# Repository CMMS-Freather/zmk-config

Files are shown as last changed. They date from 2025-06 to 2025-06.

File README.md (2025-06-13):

# HHKB Pro 2 with ZMK firmware

This project provides an out-of-tree Zephyr module and shield definition
for the HHKB Pro2 daugther board.

The `hhkb_pro2` shield defines the default HHKB keymap and `zmk,kscan`
chosen. Any board can use the `hhkb_pro2` shield by defining the
`hhkb_pro2_connector` gpio nexus node. Examples can be find in
[custom_pro2.overlay](config/boards/shields/custom_pro2/custom_pro2.overlay) and
[whkb_pro2.dts](config/boards/arm/whkb_pro2/whkb_pro2.dts).

## Customizing

Clone this repository then add your keymap overlay to the `custom_pro2` shield.
You can also create more complex customization by creating entirely new boards or
shields.

The default Github Actions will build the firmware using the [build.yml](./build.yaml)
definition.

📢 If you build some custom boards or configs, please share a picture and tips to the
[discussion](https://github.com/kanru/hhkb-zmk/discussions/11) thread!

## Build locally

Follow the steps in the [official ZMK document](https://zmk.dev/docs/user-setup) to setup build environment.

Setup Zephyr

```sh
west init -l config
west update
```

To build nice_nano_v2 based board:

```sh
west build -s zmk/app -p -b nice_nano_v2 -- \
    -DSHIELD="hhkb_pro2 custom_pro2" \
    -DZMK_CONFIG=$PWD/config
```

or to build WHKB Pro2:

```sh
west build -s zmk/app -p -b whkb_pro2 -- \
    -DSHIELD=hhkb_pro2 \
    -DZMK_CONFIG=$PWD/config
```

The finished UF2 file is at `build/zephyr/zmk.uf2`

## Soldering a custom board

The default configuration in `custom_pro2` is based on
the `nice_nano_v2` board. It only uses the pins on the
left side. The pins' order is upside down so the wires
can be bend easily under the case.

It take advantages of the high drive capability of nRF52
GPIO to power the HHKB Pro2 daughter board.

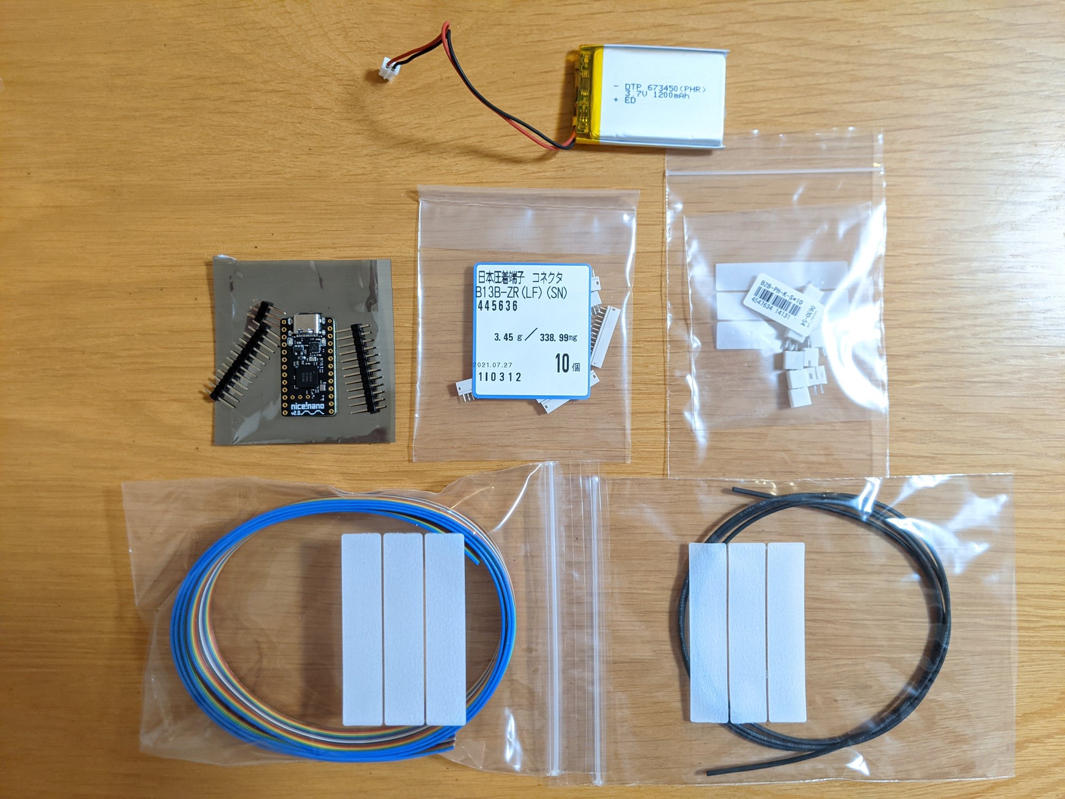
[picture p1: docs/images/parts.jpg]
parts


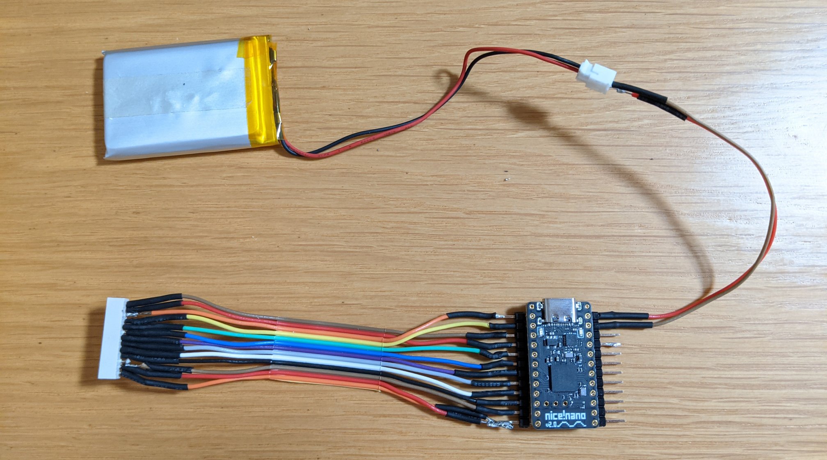
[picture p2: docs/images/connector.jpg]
connector


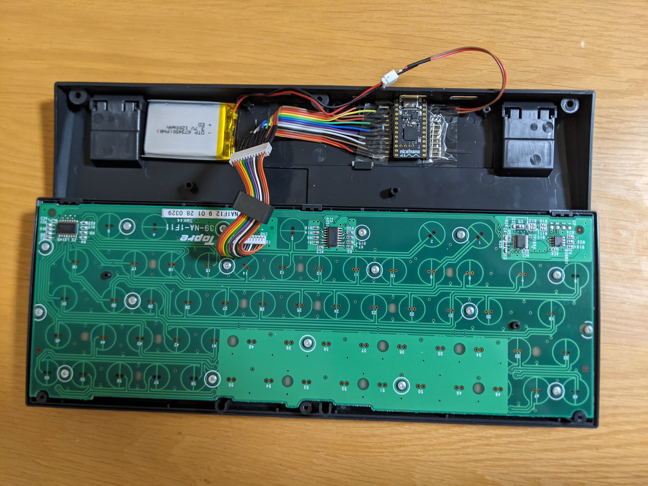
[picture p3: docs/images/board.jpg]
board


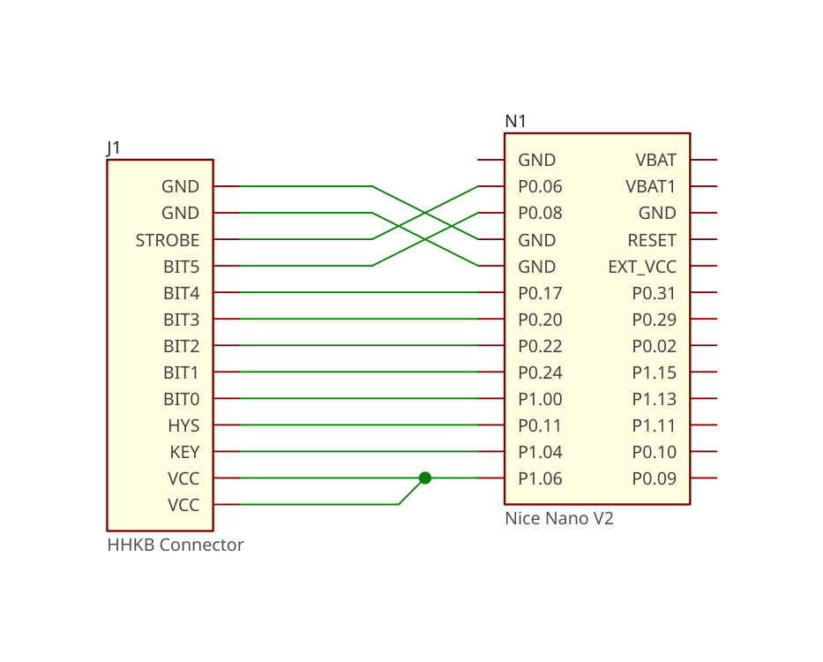
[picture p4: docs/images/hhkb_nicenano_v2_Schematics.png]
schematics


## 3D Printed Mount

The 3D printed mount (@oldmanz) is designed to fit in the HHKB Pro2 case in place of the main board. It holds the Nice!Nano, a connector for the daughter board, a reset button, and a toggle switch for power.

3D Models are in the `3d_models` directory.

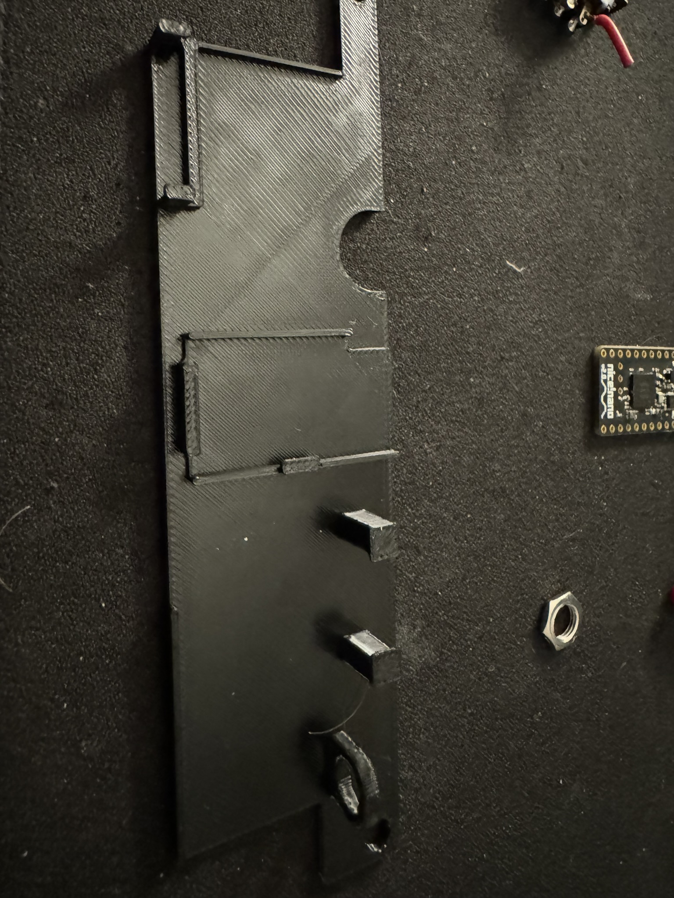
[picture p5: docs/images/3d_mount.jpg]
3d_mount


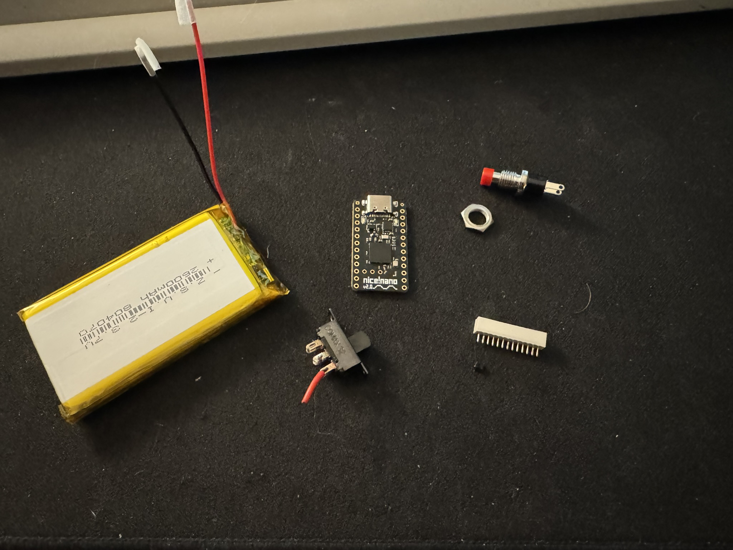
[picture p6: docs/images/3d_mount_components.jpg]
3d_mount_components


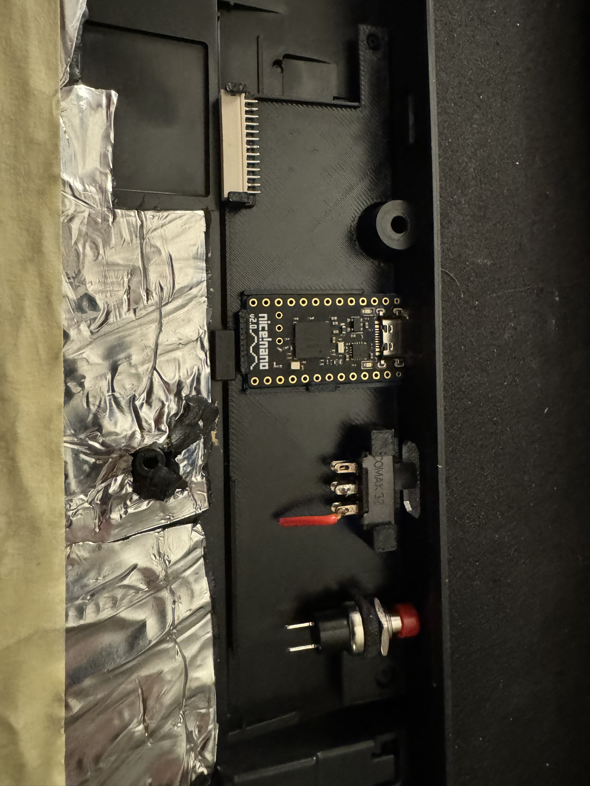
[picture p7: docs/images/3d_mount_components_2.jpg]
3d_mount_components_2


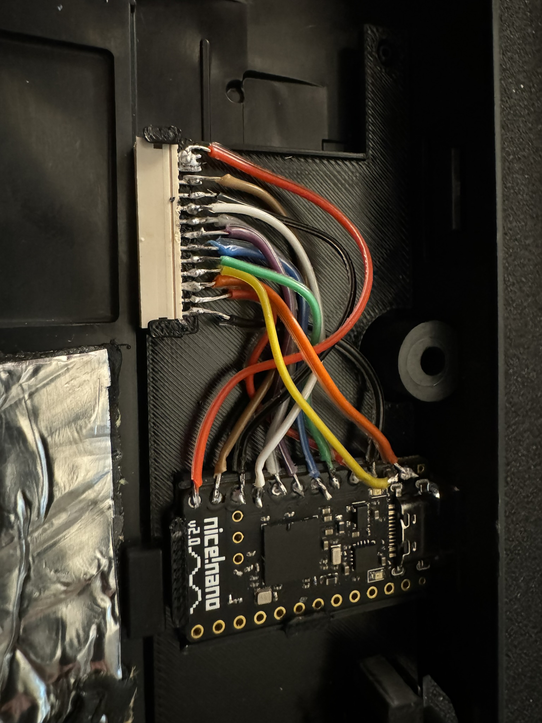
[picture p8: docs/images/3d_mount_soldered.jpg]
3d_mount_soldered_poorly


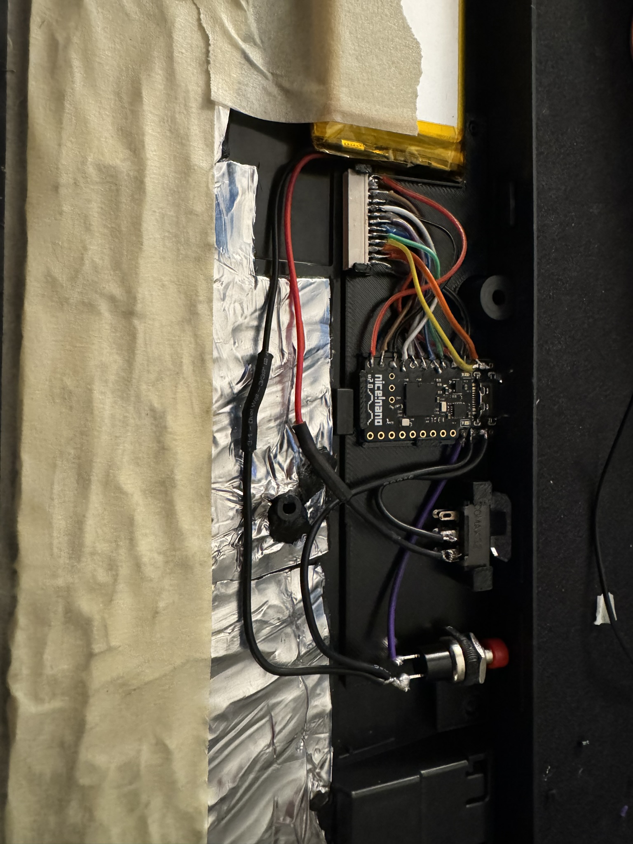
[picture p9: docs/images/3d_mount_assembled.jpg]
3d_mount_assembled


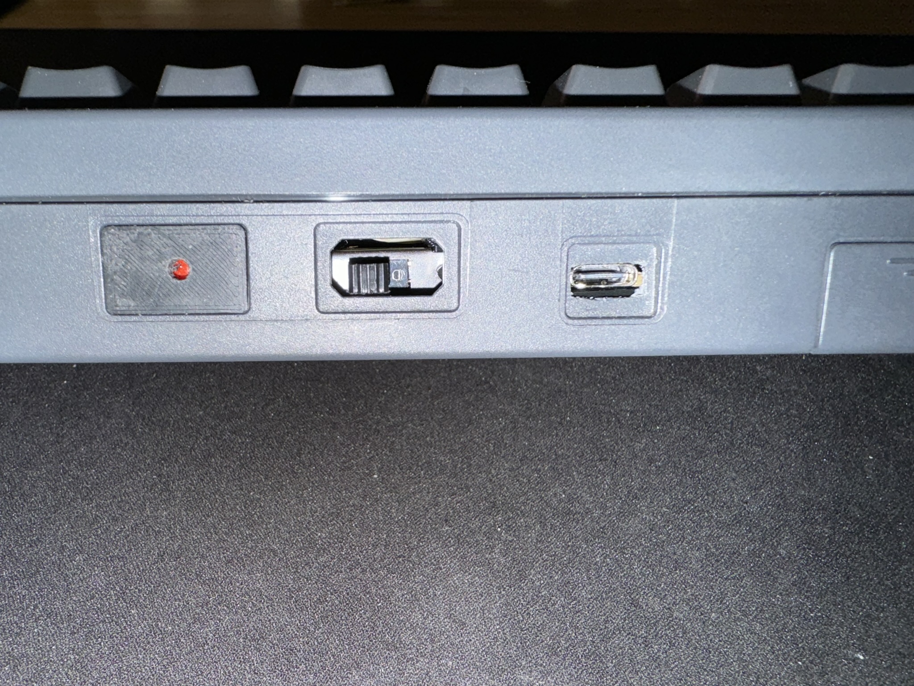
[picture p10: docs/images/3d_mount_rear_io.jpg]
3d_mount_rear_io


- The usb port will need to be filed a bit to fit usb-c.
- The switch was something I had laying around, so I am unsure of its part number.
- The reset button is behind a 3D Printed Cap, by alienman82. A hole is drilled through it.
    - https://github.com/robotmaxtron/HHKB-usb-dust-covers

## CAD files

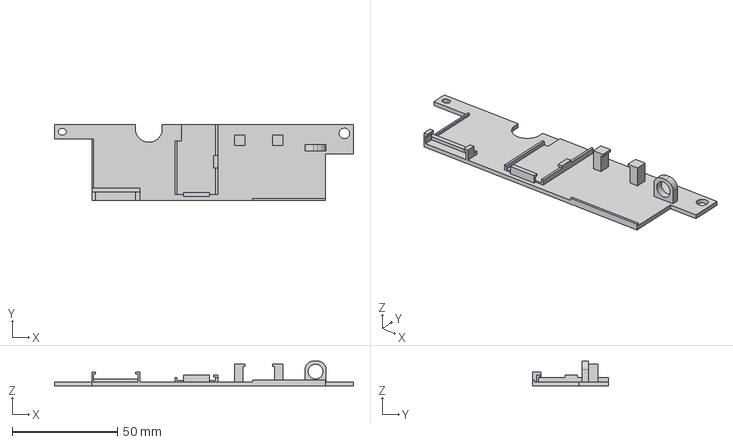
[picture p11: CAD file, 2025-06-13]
3d_models/HHKB NiceNano Mount.step
141.8 x 36.2 x 11.8 mm

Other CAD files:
3d_models/hhkb-nice-nano-mount.stl

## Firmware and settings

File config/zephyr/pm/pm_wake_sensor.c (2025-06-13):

/*
 * Copyright (c) 2023 Kan-Ru Chen
 *
 * SPDX-License-Identifier: MIT
 */

#define DT_DRV_COMPAT zmk_pm_wake_sensor

#include <zephyr/device.h>
#include <zephyr/drivers/gpio.h>

struct pm_wake_sensor_config
{
    struct gpio_dt_spec power;
    struct gpio_dt_spec sensor;
};

static int
pm_wake_sensor_init(const struct device *dev)
{
    const struct pm_wake_sensor_config *cfg = dev->config;
    gpio_pin_configure(cfg->power.port, cfg->power.pin, GPIO_OUTPUT_ACTIVE | cfg->power.dt_flags);
    gpio_pin_configure(cfg->sensor.port, cfg->sensor.pin, GPIO_INPUT | cfg->sensor.dt_flags);
    gpio_pin_interrupt_configure(cfg->sensor.port, cfg->sensor.pin, GPIO_INT_LEVEL_ACTIVE | cfg->sensor.dt_flags);

    return 0;
}

#define CREATE_PM_WAKE_SENSOR(inst)                          \
    static struct pm_wake_sensor_config config##inst = {     \
        .power = GPIO_DT_SPEC_INST_GET(inst, power_gpios),   \
        .sensor = GPIO_DT_SPEC_INST_GET(inst, sensor_gpios), \
    };                                                       \
    DEVICE_DT_INST_DEFINE(inst,                              \
                          pm_wake_sensor_init,               \
                          NULL,                              \
                          NULL,                              \
                          &config##inst,                     \
                          APPLICATION, 99,                   \
                          NULL);

DT_INST_FOREACH_STATUS_OKAY(CREATE_PM_WAKE_SENSOR)

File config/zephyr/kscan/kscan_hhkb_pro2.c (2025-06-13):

/*
 * Copyright (c) 2022, 2023 Kan-Ru Chen
 *
 * SPDX-License-Identifier: MIT
 */

#define DT_DRV_COMPAT zmk_kscan_hhkb_pro2

#include <zephyr/device.h>
#include <zephyr/drivers/kscan.h>
#include <zephyr/drivers/gpio.h>
#include <zephyr/logging/log.h>
#include <zmk/event_manager.h>
#include <zmk/events/activity_state_changed.h>

LOG_MODULE_DECLARE(zmk, CONFIG_ZMK_LOG_LEVEL);

#define MATRIX_ROWS 8
#define MATRIX_COLS 8
#define MATRIX_CELLS (MATRIX_ROWS * MATRIX_COLS)
#define SEL_PINS 6

struct kscan_hhkb_pro2_config
{
    struct gpio_dt_spec bits[SEL_PINS];
    struct gpio_dt_spec power;
    struct gpio_dt_spec key;
    struct gpio_dt_spec hys;
    struct gpio_dt_spec strobe;
    const uint16_t matrix_warm_up_ms;
    const uint16_t matrix_relax_us;
    const uint16_t adc_read_settle_us;
    const uint16_t active_polling_interval_ms;
    const uint16_t idle_polling_interval_ms;
    const uint16_t sleep_polling_interval_ms;
};

struct kscan_hhkb_pro2_data
{
    kscan_callback_t callback;
    uint16_t poll_interval;
    struct k_work_delayable poll;
    bool matrix_state[MATRIX_CELLS];
    const struct device *dev;
};

static int kscan_hhkb_pro2_configure(const struct device *dev, kscan_callback_t callback)
{
    LOG_DBG("KSCAN API configure");
    struct kscan_hhkb_pro2_data *data = dev->data;
    if (!callback)
    {
        return -EINVAL;
    }
    data->callback = callback;
    LOG_DBG("Configured KSCAN");
    return 0;
}

static int kscan_hhkb_pro2_enable(const struct device *dev)
{
    LOG_DBG("KSCAN API enable");
    struct kscan_hhkb_pro2_data *data = dev->data;
    k_work_schedule(&data->poll, K_MSEC(data->poll_interval));
    return 0;
}

static int kscan_hhkb_pro2_disable(const struct device *dev)
{
    LOG_DBG("KSCAN API disable");
    struct kscan_hhkb_pro2_data *data = dev->data;
    k_work_cancel_delayable(&data->poll);
    return 0;
}

static void kscan_hhkb_pro2_work_handler(struct k_work *work)
{
    struct k_work_delayable *d_work = k_work_delayable_from_work(work);
    struct kscan_hhkb_pro2_data *data = CONTAINER_OF(d_work, struct kscan_hhkb_pro2_data, poll);
    const struct device *dev = data->dev;
    const struct kscan_hhkb_pro2_config *cfg = dev->config;
    bool matrix_read[MATRIX_CELLS];

    // Power on everything
    gpio_pin_configure(cfg->key.port, cfg->key.pin, GPIO_INPUT | cfg->key.dt_flags);
    gpio_pin_set(cfg->strobe.port, cfg->strobe.pin, 1);
    gpio_pin_set(cfg->power.port, cfg->power.pin, 1);
    // The board needs some time to be operational after powering up
    k_sleep(K_MSEC(cfg->matrix_warm_up_ms));
    for (int r = 0; r < MATRIX_ROWS; ++r)
    {
        for (int c = 0; c < MATRIX_COLS; ++c)
        {
            gpio_pin_set(cfg->bits[0].port, cfg->bits[0].pin, r & BIT(0));
            gpio_pin_set(cfg->bits[1].port, cfg->bits[1].pin, r & BIT(1));
            gpio_pin_set(cfg->bits[2].port, cfg->bits[2].pin, r & BIT(2));
            gpio_pin_set(cfg->bits[3].port, cfg->bits[3].pin, c & BIT(0));
            gpio_pin_set(cfg->bits[4].port, cfg->bits[4].pin, c & BIT(1));
            gpio_pin_set(cfg->bits[5].port, cfg->bits[5].pin, c & BIT(2));

            int cell = (r * MATRIX_COLS) + c;
            const bool prev = data->matrix_state[cell];
            gpio_pin_set(cfg->hys.port, cfg->hys.pin, prev);

            k_busy_wait(cfg->matrix_relax_us);

            const unsigned int lock = irq_lock();
            // Pull low strobe line to trigger sensing
            gpio_pin_set(cfg->strobe.port, cfg->strobe.pin, 0);
            gpio_pin_set(cfg->strobe.port, cfg->strobe.pin, 1);
            k_busy_wait(cfg->adc_read_settle_us);
            const bool pressed = gpio_pin_get(cfg->key.port, cfg->key.pin);
            irq_unlock(lock);
            gpio_pin_set(cfg->hys.port, cfg->hys.pin, 0);

            matrix_read[cell] = pressed;
        }
    }
    // Set all gpio pins to low and power off the controller board to avoid
    // current leakage.
    for (int i = 0; i < SEL_PINS; ++i)
    {
        gpio_pin_set(cfg->bits[i].port, cfg->bits[i].pin, 0);
    }
    gpio_pin_configure(cfg->key.port, cfg->key.pin, GPIO_DISCONNECTED);
    gpio_pin_set(cfg->power.port, cfg->power.pin, 0);
    gpio_pin_set(cfg->strobe.port, cfg->strobe.pin, 0);

    for (int r = 0; r < MATRIX_ROWS; ++r)
    {
        for (int c = 0; c < MATRIX_COLS; ++c)
        {
            int cell = (r * MATRIX_COLS) + c;
            if (data->matrix_state[cell] != matrix_read[cell])
            {
                data->matrix_state[cell] = matrix_read[cell];
                data->callback(data->dev, r, c, matrix_read[cell]);
            }
        }
    }
    k_work_schedule(&data->poll, K_MSEC(data->poll_interval));
}

static int kscan_hhkb_pro2_activity_event_handler(const struct device *dev, const zmk_event_t *eh)
{
    struct zmk_activity_state_changed *ev = as_zmk_activity_state_changed(eh);
    if (ev == NULL)
    {
        return -ENOTSUP;
    }
    struct kscan_hhkb_pro2_data *data = dev->data;
    const struct kscan_hhkb_pro2_config *cfg = dev->config;
    switch (ev->state)
    {
    case ZMK_ACTIVITY_ACTIVE:
        data->poll_interval = cfg->active_polling_interval_ms;
        break;
    case ZMK_ACTIVITY_IDLE:
        data->poll_interval = cfg->idle_polling_interval_ms;
        break;
    case ZMK_ACTIVITY_SLEEP:
        data->poll_interval = cfg->sleep_polling_interval_ms;
        break;
    default:
        LOG_WRN("Unhandled activity state: %d", ev->state);
        return -EINVAL;
    }
    LOG_DBG("Setting poll interval to %d", data->poll_interval);
    return 0;
}

static int kscan_hhkb_pro2_init(const struct device *dev)
{
    LOG_DBG("KSCAN init");
    struct kscan_hhkb_pro2_data *data = dev->data;
    const struct kscan_hhkb_pro2_config *cfg = dev->config;
    data->dev = dev;
    for (int i = 0; i < SEL_PINS; ++i)
    {
        gpio_pin_configure(cfg->bits[i].port,
                           cfg->bits[i].pin,
                           GPIO_OUTPUT_INACTIVE | cfg->bits[i].dt_flags);
    }
    gpio_pin_configure(cfg->power.port, cfg->power.pin, GPIO_OUTPUT_INACTIVE | cfg->power.dt_flags);
    // Disconnect input pin to save power.
    gpio_pin_configure(cfg->key.port, cfg->key.pin, GPIO_DISCONNECTED);
    gpio_pin_configure(cfg->hys.port, cfg->hys.pin, GPIO_OUTPUT_INACTIVE | cfg->hys.dt_flags);
    gpio_pin_configure(cfg->strobe.port, cfg->strobe.pin, GPIO_OUTPUT_INACTIVE | cfg->strobe.dt_flags);

    data->poll_interval = cfg->active_polling_interval_ms;
    k_work_init_delayable(&data->poll, kscan_hhkb_pro2_work_handler);
    k_work_schedule(&data->poll, K_MSEC(data->poll_interval));

    return 0;
}
static const struct kscan_driver_api kscan_hhkb_pro2_api = {
    .config = kscan_hhkb_pro2_configure,
    .enable_callback = kscan_hhkb_pro2_enable,
    .disable_callback = kscan_hhkb_pro2_disable,
};
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
